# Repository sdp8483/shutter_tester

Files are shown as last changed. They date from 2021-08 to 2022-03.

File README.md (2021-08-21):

# Shutter Tester
Light sensor array for measuring shutter timing of SLR cameras.

## Directory Outline
- [`~/pcb/`](pcb) is for KiCAD desinge files. When starting a new KiCAD project in this directory be sure to uncheck *Create a new direcotry for the project* in the **Create New Project** window.
- [`~/firmware/`](firmware) is for firmware souce code and binaries.
- [`~/enclosure/`](enclosure) is for mechanical CAD design files for the encloser or box. Create seperate directories for `.stl` or other files for 3d printing for easy accesss.

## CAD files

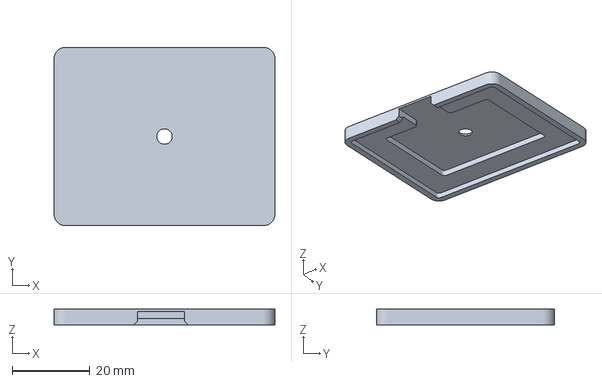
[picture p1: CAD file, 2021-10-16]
enclosure/shutter_tester-Body.amf
57.0 x 46.0 x 4.00 mm

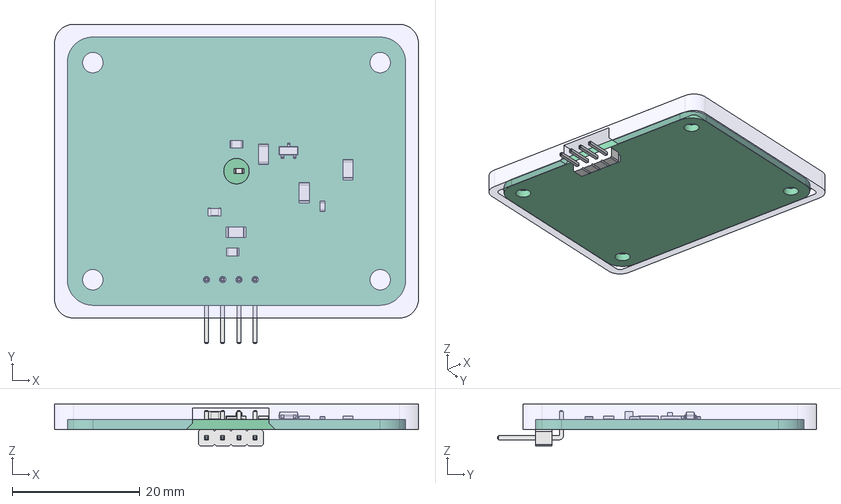
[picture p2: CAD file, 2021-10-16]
enclosure/shutter_tester.FCStd
57.0 x 50.0 x 6.54 mm
Pcb_4d56
J1_PinHeader_1x04_P254mm_Horizontal_6169FA07
JP1_R_1206_3216Metric_616AD7BC x 4
C1_C_0805_2012Metric_616A0DC5
R6_R_0805_2012Metric_616A0CF3 x 2
R5_R_0603_1608Metric_616A0D26
D1_LED_0603_1608Metric_6120F61D
Q1_SOT_23_6121188E

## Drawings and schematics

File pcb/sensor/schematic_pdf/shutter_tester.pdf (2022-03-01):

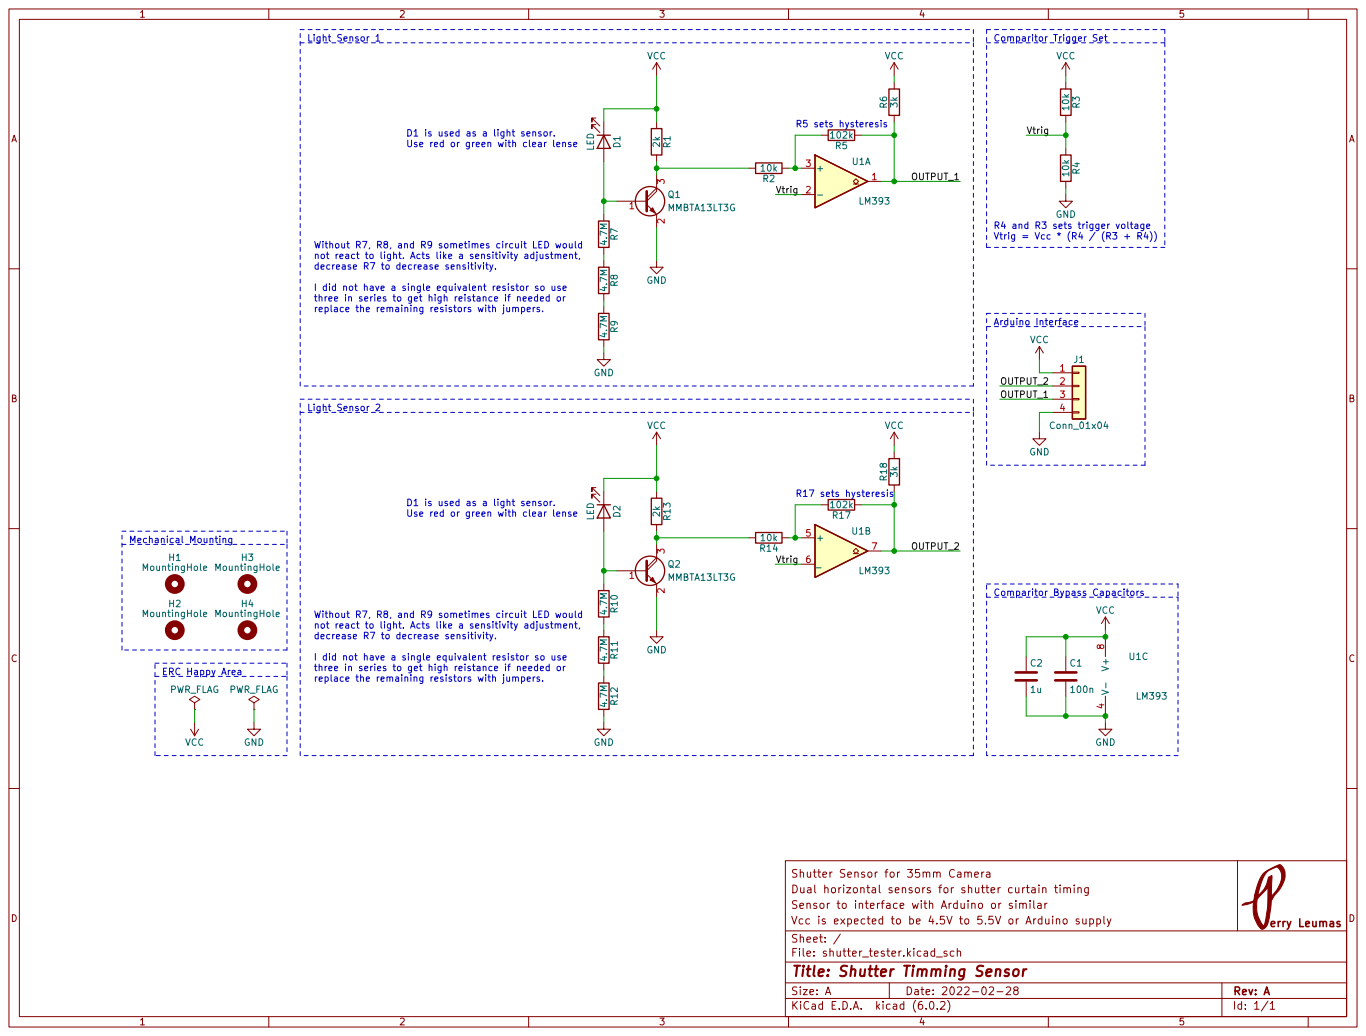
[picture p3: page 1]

Vtrig = Vcc * (R4 / (R3 + R4)) Arduino Interface Comparitor Trigger Set

R5 sets hysteresis Without R7, R8, and R9 sometimes circuit LED would not react to light. Acts like a sensitivity adjustment,

D1 is used as a light sensor.
Use red or green with clear lense

R4 and R3 sets trigger voltage

Light Sensor 2 Without R7, R8, and R9 sometimes circuit LED would not react to light. Acts like a sensitivity adjustment,

decrease R7 to decrease sensitivity.

I did not have a single equivalent resistor so use
three in series to get high reistance if needed or
replace the remaining resistors with jumpers.

Id: 1/1 Title: Shutter Timming Sensor

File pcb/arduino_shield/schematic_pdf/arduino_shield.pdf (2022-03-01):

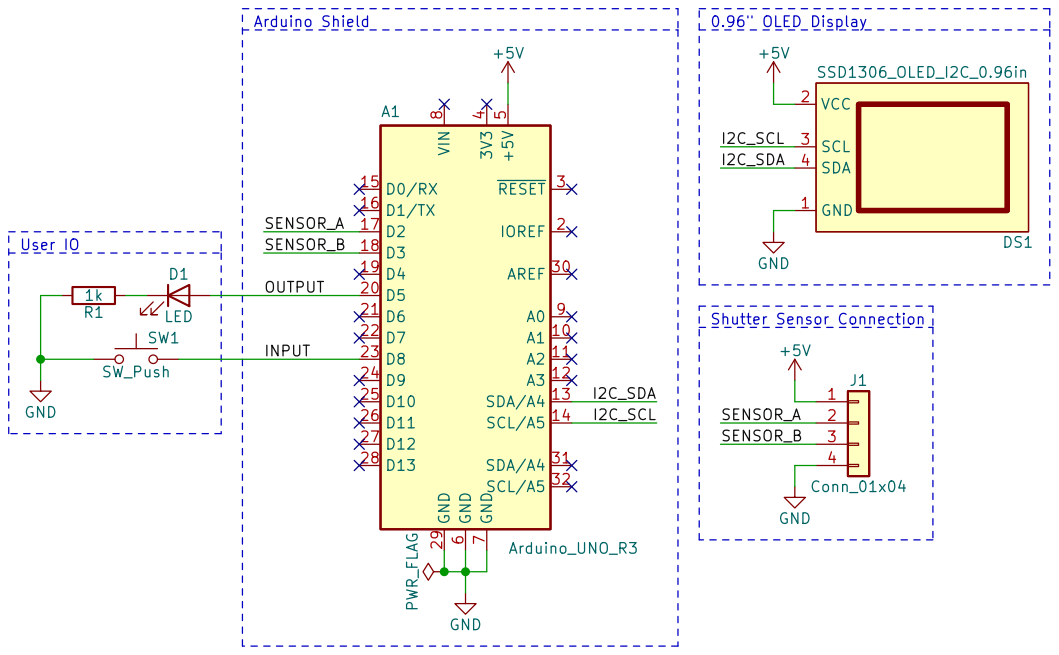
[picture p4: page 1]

8 A0 9 A1 Arduino_UNO_R3 +5V +5V GND 1 VCC 2 SCL 3 SDA 4 DS1 SSD1306_OLED_I2C_0.96in GND

Id: 1/1 Title: Shutter Timming Sensor Arduino Shield

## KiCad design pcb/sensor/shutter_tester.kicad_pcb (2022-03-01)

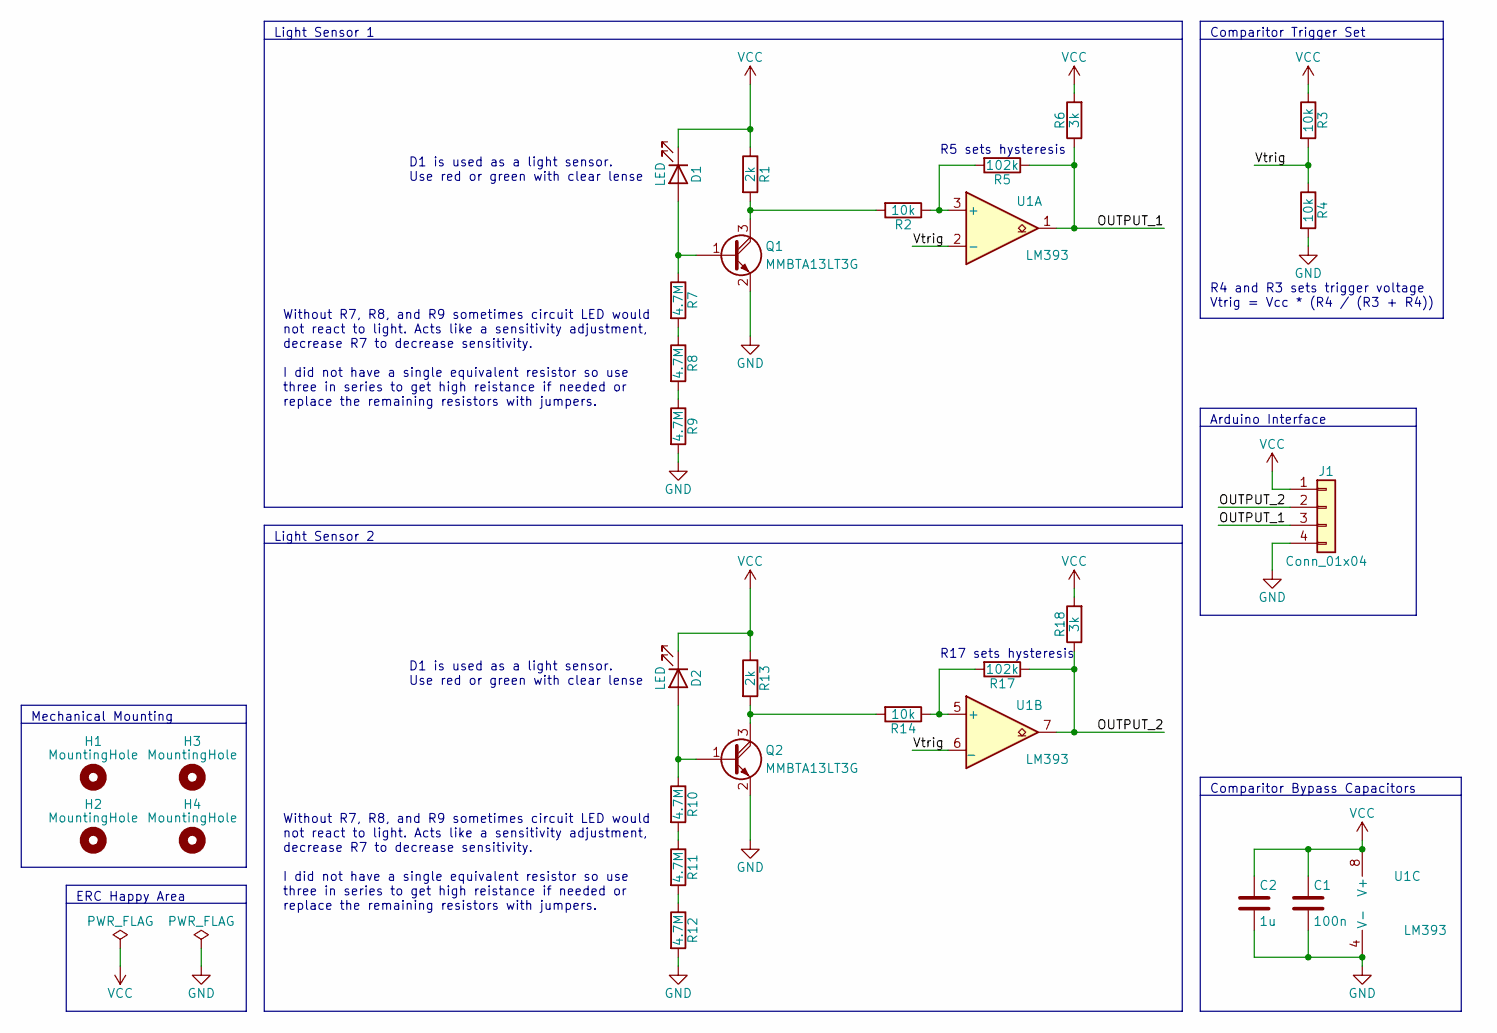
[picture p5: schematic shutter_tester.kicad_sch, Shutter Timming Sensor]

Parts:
C1: 100n; C_0805_2012Metric_Pad1.18x1.45mm_HandSolder
C2: 1u; C_0805_2012Metric_Pad1.18x1.45mm_HandSolder
D1, D2: LED; LED_0805_2012Metric_Pad1.15x1.40mm_HandSolder
H1, H2, H3, H4: MountingHole; MountingHole_3.2mm_M3
J1: Conn_01x04; PinHeader_1x04_P2.54mm_Vertical
Q1, Q2: MMBTA13LT3G; SOT-23
R1, R13: 2k; R_0805_2012Metric_Pad1.20x1.40mm_HandSolder
R2, R3, R4, R14: 10k; R_0603_1608Metric_Pad0.98x0.95mm_HandSolder
R5, R17: 102k; R_0603_1608Metric_Pad0.98x0.95mm_HandSolder
R6, R18: 3k; R_0805_2012Metric_Pad1.20x1.40mm_HandSolder
R7, R8, R9, R10, R11, R12: 4.7M; R_0603_1608Metric_Pad0.98x0.95mm_HandSolder
U1: LM393; SOP-8_3.9x4.9mm_P1.27mm

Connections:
/OUTPUT_1: J1.3, R5.1, R6.1, U1.1
/OUTPUT_2: J1.2, R17.1, R18.1, U1.7
/Vtrig: R3.2, R4.1, U1.2 (-), U1.6 (_)
GND: C1.2, C2.2, J1.4, Q1.2 (E), Q2.2 (E), R4.2, R9.2, R12.2, U1.4 (V-)
unnamed: D1.2 (A), Q1.1 (B), R7.1
unnamed: D2.2 (A), Q2.1 (B), R10.1
unnamed: Q1.3 (C), R1.2, R2.2
unnamed: Q2.3 (C), R13.2, R14.2
unnamed: R2.1, R5.2, U1.3 (+)
unnamed: R7.2, R8.1
unnamed: R8.2, R9.1
unnamed: R10.2, R11.1
unnamed: R11.2, R12.1
unnamed: R14.1, R17.2, U1.5 (+)
VCC: C1.1, C2.1, D1.1 (K), D2.1 (K), J1.1, R1.1, R3.1, R6.2, R13.1, R18.2, U1.8 (V+)

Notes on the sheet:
Arduino Interface
Light Sensor 1
Comparitor Trigger Set
Without R7, R8, and R9 sometimes circuit LED would not react to light. Acts like a sensitivity adjustment, decrease R7 to decrease sensitivity. I did not have a single equivalent resistor so use three in series to get high reistance if needed or replace the remaining resistors with jumpers.
R4 and R3 sets trigger voltage Vtrig = Vcc * (R4 / (R3 + R4))
Light Sensor 2
D1 is used as a light sensor. Use red or green with clear lense
R17 sets hysteresis
Comparitor Bypass Capacitors
R5 sets hysteresis
Mechanical Mounting
ERC Happy Area

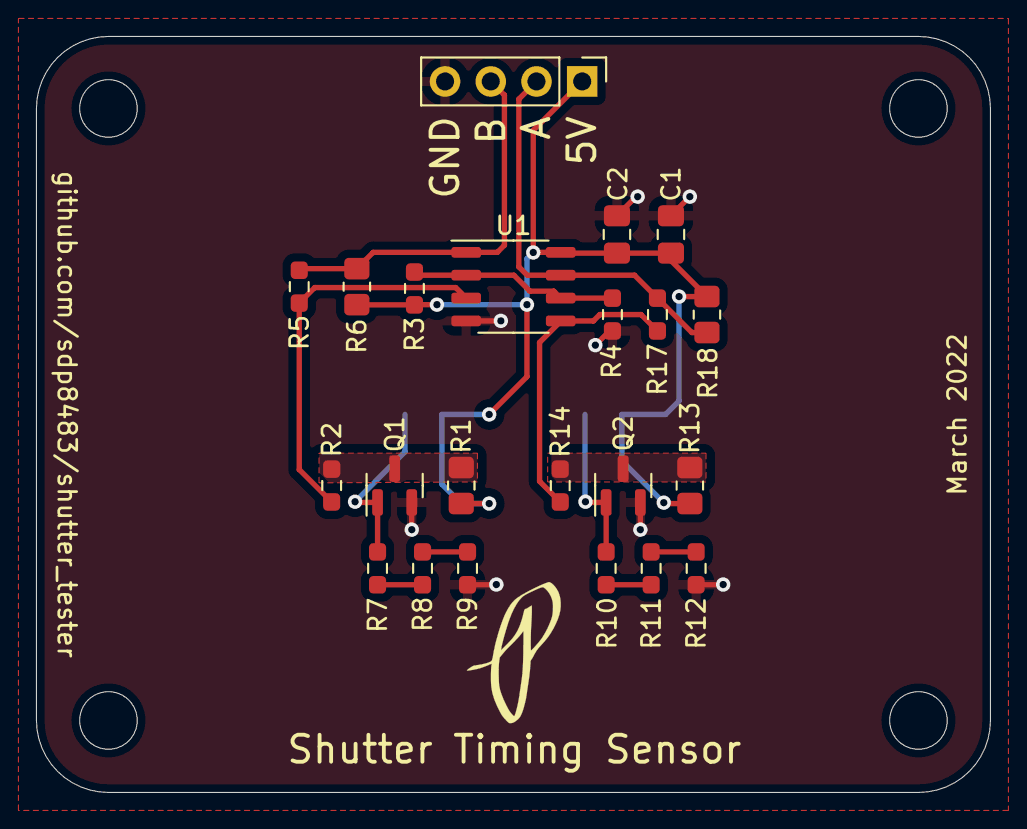
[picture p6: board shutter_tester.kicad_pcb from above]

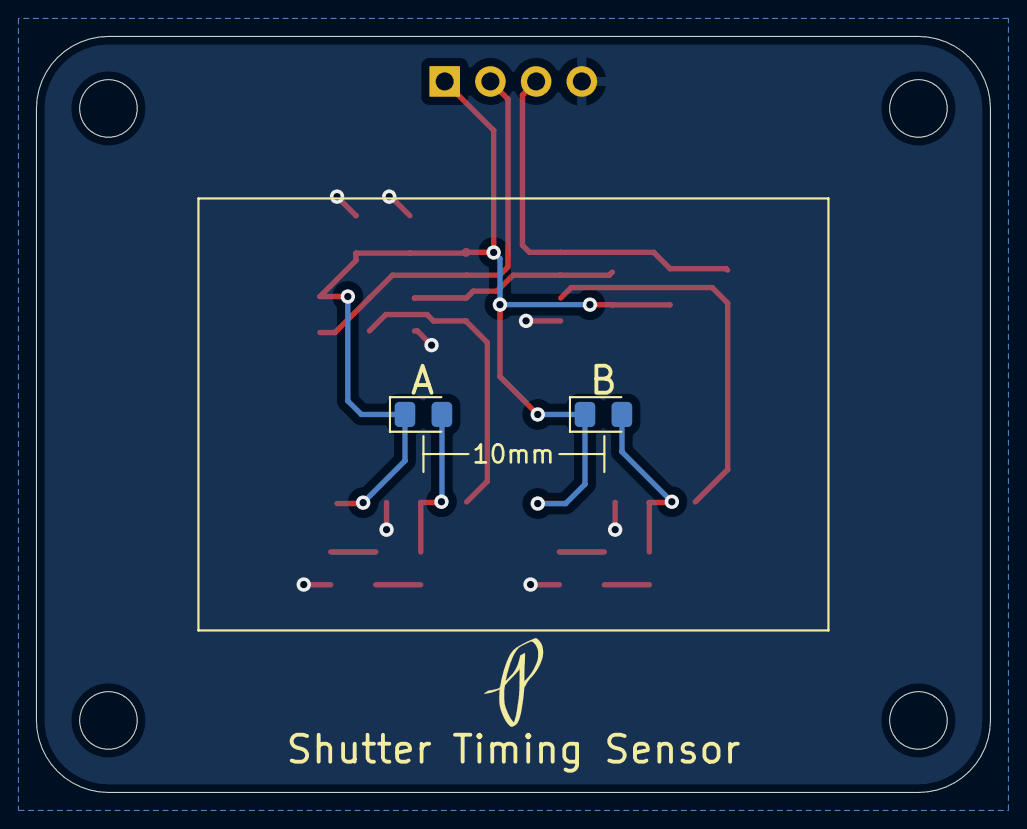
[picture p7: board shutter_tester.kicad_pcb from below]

Board: 2 copper layers, 53.0 x 42.0 mm, 28 parts (2 on the bottom side), 15 nets.

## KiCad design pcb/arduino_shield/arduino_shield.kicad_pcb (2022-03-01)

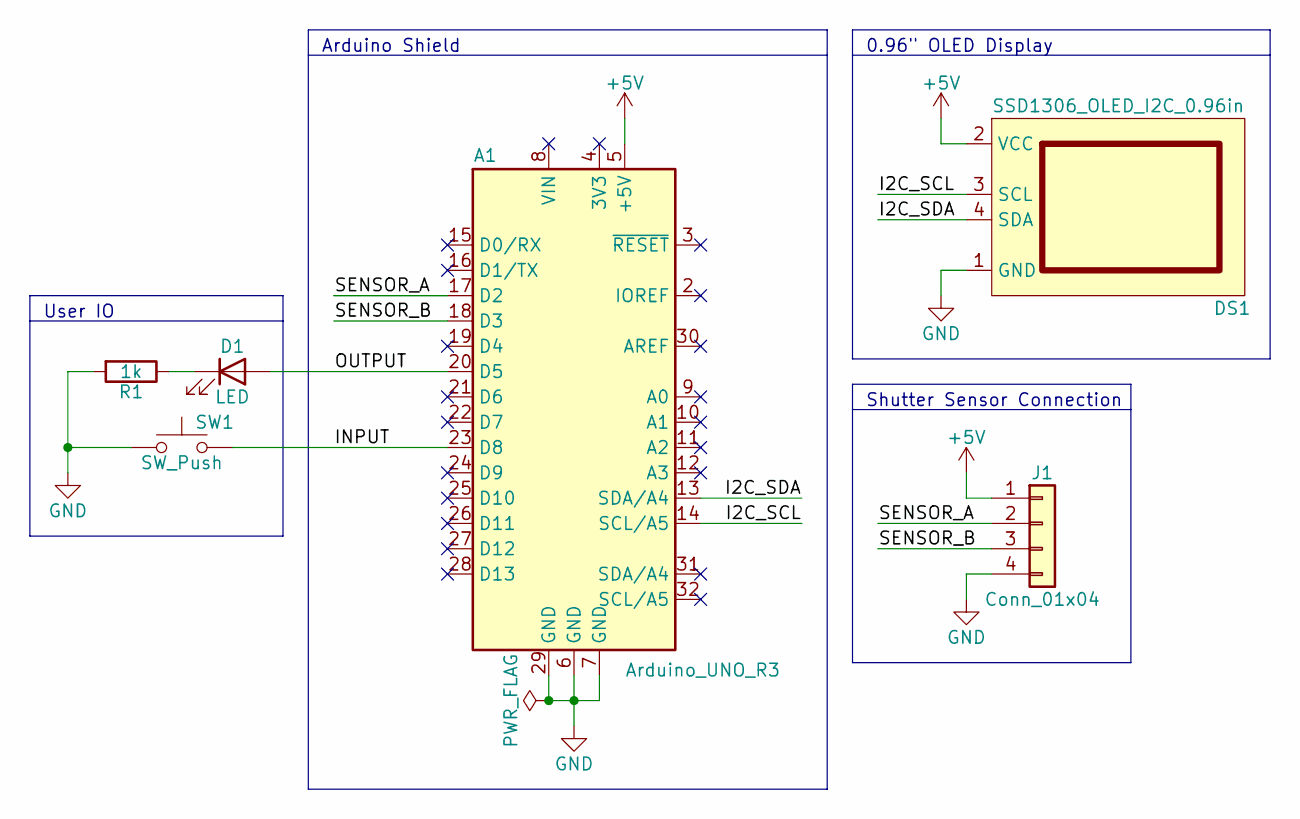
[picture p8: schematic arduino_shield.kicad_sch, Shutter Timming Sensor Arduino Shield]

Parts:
A1: Arduino_UNO_R3
D1: LED; LED_0805_2012Metric_Pad1.15x1.40mm_HandSolder
DS1: SSD1306_OLED_I2C_0.96in; ssd1306_oled_i2c_0.96in
J1: Conn_01x04; PinHeader_1x04_P2.54mm_Vertical
R1: 1k; R_0603_1608Metric_Pad0.98x0.95mm_HandSolder
SW1: SW_Push; SW_PUSH_6mm

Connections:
+5V: A1.5 (+5V), DS1.2 (VCC), J1.1
/I2C_SCL: A1.14 (SCL/A5), DS1.3 (SCL)
/I2C_SDA: A1.13 (SDA/A4), DS1.4 (SDA)
/INPUT: A1.23 (D8), SW1.2
/OUTPUT: A1.20 (D5), D1.2 (A)
/SENSOR_A: A1.17 (D2), J1.2
/SENSOR_B: A1.18 (D3), J1.3
GND: A1.6 (GND), A1.7 (GND), A1.29 (GND), DS1.1 (GND), J1.4, R1.2, SW1.1
unnamed: D1.1 (K), R1.1

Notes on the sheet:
User IO
Arduino Shield
Shutter Sensor Connection
0.96" OLED Display

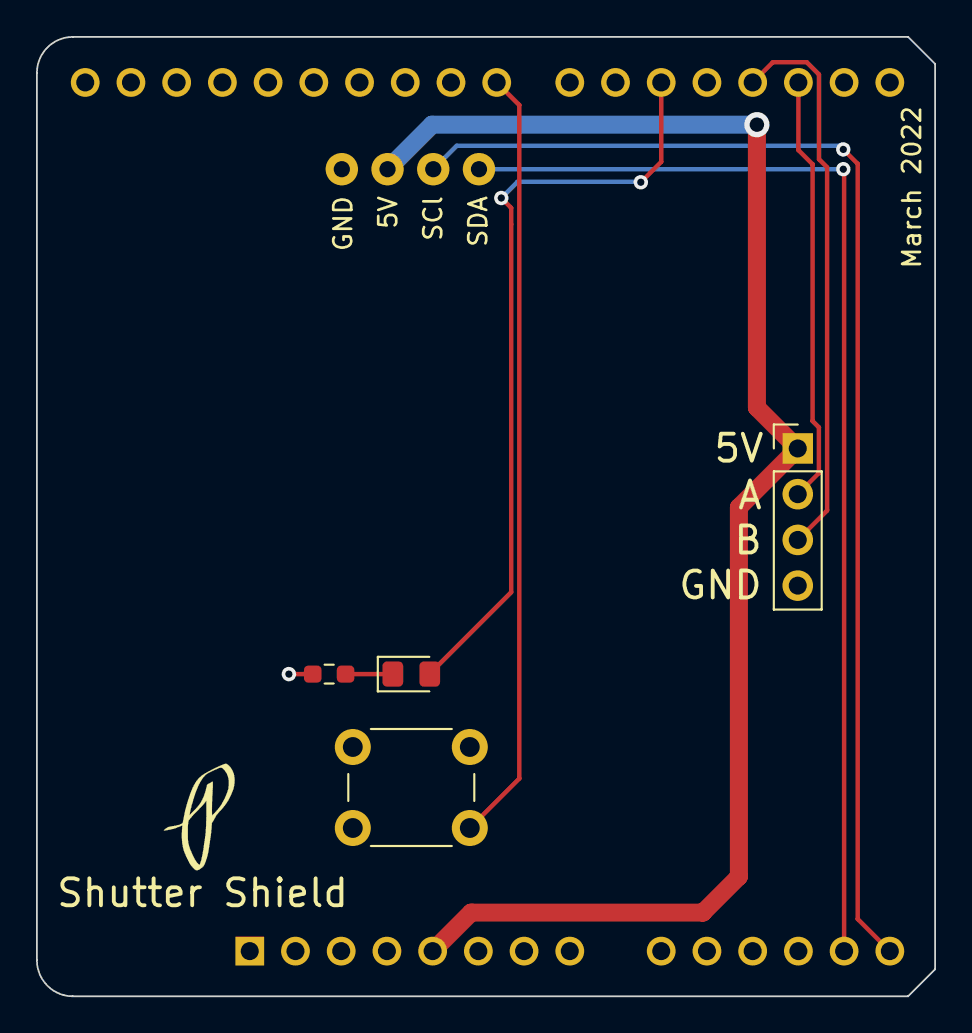
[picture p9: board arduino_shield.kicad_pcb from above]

Board: 2 copper layers, 49.9 x 53.3 mm, 6 parts (1 on the bottom side), 9 nets.

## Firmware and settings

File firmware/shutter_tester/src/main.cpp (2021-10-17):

#include <Arduino.h>
#include <SPI.h>
#include <Wire.h>
#include <Adafruit_GFX.h>
#include <Adafruit_SSD1306.h>

#define SCREEN_WIDTH 128      // OLED display width, in pixels
#define SCREEN_HEIGHT 64      // OLED display height, in pixels

#define SHUTTER_SENSOR_PIN  2
#define SERIAL_BAUD         115200

// Declaration for an SSD1306 display connected to I2C (SDA, SCL pins)
// The pins for I2C are defined by the Wire-library. 
// On an arduino UNO:       A4(SDA), A5(SCL)
#define OLED_RESET          -1      // Reset pin # (or -1 if sharing Arduino reset pin)
#define SCREEN_ADDRESS      0x3C    // See datasheet for Address; 0x3D for 128x64, 0x3C for 128x32

/* User Typedef -------------------------------------------------------------- */
typedef enum __edge_t {
  NO_EDGE,
  FALLING_EDGE,
  RISING_EDGE,
  CALC_EDGE,
} edge_t;

typedef struct __shutterSpeed_handle_t {
  unsigned long start;
  unsigned long stop;
  edge_t edge;
  edge_t edge_to_detect;
  unsigned long duration_us;
  double duration_sec;
  double speed;
} ShutterSpeed_Handle_t;

/* Global Variables ---------------------------------------------------------- */
ShutterSpeed_Handle_t shutter;
Adafruit_SSD1306 display(SCREEN_WIDTH, SCREEN_HEIGHT, &Wire, OLED_RESET);

/* Function Prototypes ------------------------------------------------------- */ 
void shutter_isr(void);
void shutter_init(ShutterSpeed_Handle_t *shutter);
void drawScreen(Adafruit_SSD1306 *display, ShutterSpeed_Handle_t *shutter);

void setup() {
  Serial.begin(SERIAL_BAUD);

  // SSD1306_SWITCHCAPVCC = generate display voltage from 3.3V internally
  if(!display.begin(SSD1306_SWITCHCAPVCC, SCREEN_ADDRESS)) {
    Serial.println(F("SSD1306 allocation failed"));
    for(;;); // Don't proceed, loop forever
  }

  shutter_init(&shutter);               /* initialize shutter variable */
  
  drawScreen(&display, &shutter);                 /* draw display */

  pinMode(SHUTTER_SENSOR_PIN, INPUT);   /* shutter sensor pin is input */

  attachInterrupt(digitalPinToInterrupt(SHUTTER_SENSOR_PIN), shutter_isr, FALLING);
} // end setup()

void loop() {
  switch (shutter.edge) {
    case FALLING_EDGE:
      detachInterrupt(digitalPinToInterrupt(SHUTTER_SENSOR_PIN));
      shutter.edge = NO_EDGE;
      shutter.edge_to_detect = RISING_EDGE;
      shutter.start = micros();
      attachInterrupt(digitalPinToInterrupt(SHUTTER_SENSOR_PIN), shutter_isr, RISING);
      break;
    case RISING_EDGE:
      detachInterrupt(digitalPinToInterrupt(SHUTTER_SENSOR_PIN));
      shutter.edge = CALC_EDGE;
      shutter.stop = micros();
      
      break;
    case CALC_EDGE:
      shutter.duration_us = shutter.stop - shutter.start;
      shutter.duration_sec = shutter.duration_us / 1e6;
      shutter.speed = 1 / shutter.duration_sec;

      drawScreen(&display, &shutter);

      Serial.print(F("Start: "));
      Serial.print(shutter.start);
      Serial.print(F("us \nStop: "));
      Serial.print(shutter.stop);
      Serial.print(F("us \nDuration: "));
      Serial.print(shutter.duration_us);
      Serial.print(F("us \nSpeed: 1/"));
      Serial.println(shutter.speed);
      Serial.println();

      shutter_init(&shutter);               /* reset shutter variable */

      attachInterrupt(digitalPinToInterrupt(SHUTTER_SENSOR_PIN), shutter_isr, FALLING);

      break;
    
    case NO_EDGE:

      break;

    default:
      shutter.edge = NO_EDGE;
      break;
  }

} // end loop()

void shutter_isr(void) {
  shutter.edge = shutter.edge_to_detect;
} // end shutter_isr()

/* Set/Reset ShutterSpeed_Handle --------------------------------------------- */
void shutter_init(ShutterSpeed_Handle_t *shutter) {
  shutter->start = 0;
  shutter->stop = 0;
  shutter->duration_us = 0;
  shutter->duration_sec = 0;
  shutter->speed = 0;
  shutter->edge = NO_EDGE;
  shutter->edge_to_detect = FALLING_EDGE;
} // end shutter_init()

/* display measurement to SSD1306 display ------------------------------------ */
void drawScreen(Adafruit_SSD1306 *display, ShutterSpeed_Handle_t *shutter) {
  display->clearDisplay();

  display->setTextSize(1);
  display->setTextColor(SSD1306_WHITE);
  
  display->drawRect(0, 0, display->width(), 11, SSD1306_WHITE);

  display->setCursor(2, 2);   // top left corner
  display->print(F("Shutter Tester"));

  display->setCursor(0, 12);
  display->print(F("Start: "));
  display->print(shutter->start);
  display->print("us");

  display->setCursor(0, 20);
  display->print(F("Stop:  "));
  display->print(shutter->stop);
  display->print("us");

  display->setCursor(0, 28);
  display->print(F("Duration: "));
  display->print(shutter->duration_us);
  display->print("us");

  display->setCursor(0, 38);
  display->setTextSize(2);

  if (shutter->speed > 1.0) {
    display->print(F("1/"));
    display->print(shutter->speed);
  } else {
    display->print(shutter->duration_sec);
    display->print(F("sec"));
  }
  
  display->display();

}

// void testdrawchar(void) {
//   display.clearDisplay();

//   display.setTextSize(1);      // Normal 1:1 pixel scale
//   display.setTextColor(SSD1306_WHITE); // Draw white text
//   display.setCursor(0, 0);     // Start at top-left corner
//   display.cp437(true);         // Use full 256 char 'Code Page 437' font

//   // Not all the characters will fit on the display. This is normal.
//   // Library will draw what it can and the rest will be clipped.
//   for(int16_t i=0; i<256; i++) {
//     if(i == '\n') display.write(' ');
//     else          display.write(i);
//   }

//   display.display();
//   delay(2000);
// }

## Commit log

2021-08-21 init commit
    [shutter_tester.kicad_pcb, shutter_tester.sch]
2021-08-21 first draft pcb
    [shutter_tester.kicad_pcb, shutter_tester.sch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]
2021-10-07 change to single light sensor
    [shutter_tester.kicad_pcb, shutter_tester.sch]
2021-10-07 generate new gcode
    [shutter_tester-B_Cu.gbr, shutter_tester-Edge_Cuts.gbr, shutter_tester-job.gbrjob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]
2021-10-13 no print !
2021-10-16 add comparator circuit
    [shutter_tester.kicad_pcb, shutter_tester.sch]
2021-10-16 move tracks for engraving tip access
    [shutter_tester.kicad_pcb]
2021-10-16 export to gerber
    [shutter_tester-B_Cu.gbr, shutter_tester-Edge_Cuts.gbr, shutter_tester-job.gbrjob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]
2021-10-16 simple cover
    [shutter_tester-Body.amf, shutter_tester.FCStd]
2021-10-16 add pulldown resistor to darlington
    [shutter_tester.kicad_pcb, shutter_tester.sch]
2021-10-16 update with new pulldown
    [shutter_tester-B_Cu.gbr, shutter_tester-Edge_Cuts.gbr, shutter_tester-job.gbrjob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]
2021-10-21 add notes to circuit
    [shutter_tester.sch]
2022-02-28 zip up pcb mill version
    [shutter_tester-B_Cu.gbr, shutter_tester-Edge_Cuts.gbr, shutter_tester-job.gbrjob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]
2022-02-28 convert to kicad 6
    [shutter_tester.kicad_pcb, shutter_tester.kicad_sch, shutter_tester.sch]
2022-03-01 getting to rev b layout
    [shutter_tester.kicad_pcb, shutter_tester.kicad_sch]
2022-03-01 rev a layout
    [shutter_tester.kicad_pcb, shutter_tester.kicad_sch]
2022-03-01 move to new dir
    [shutter_tester.kicad_pcb, shutter_tester.kicad_sch]
2022-03-01 new pcb
2022-03-01 shutter shield
    [arduino_shield.kicad_pcb, arduino_shield.kicad_sch]
2022-03-01 add github link
    [shutter_tester.kicad_pcb]
2022-03-01 export schma pdf
    [arduino_shield.kicad_sch]
2022-03-01 export pcb to gerber
    [arduino_shield-B_Cu.gbr, arduino_shield-B_Mask.gbr, arduino_shield-B_Paste.gbr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]
